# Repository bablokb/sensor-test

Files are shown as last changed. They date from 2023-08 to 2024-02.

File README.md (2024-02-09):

Sensor-Test
===========

This repository contains data and plots of a large scale non-scientifc
comparison test of various temperature/humidity sensors.

Test-Setup
----------

Eight different sensors with a total of 21 units were tested simultaniously
using two Raspberry Pi Picos
(see [Pico-Datalogger](https://github.com/bablokb/pcb-pico-datalogger)).

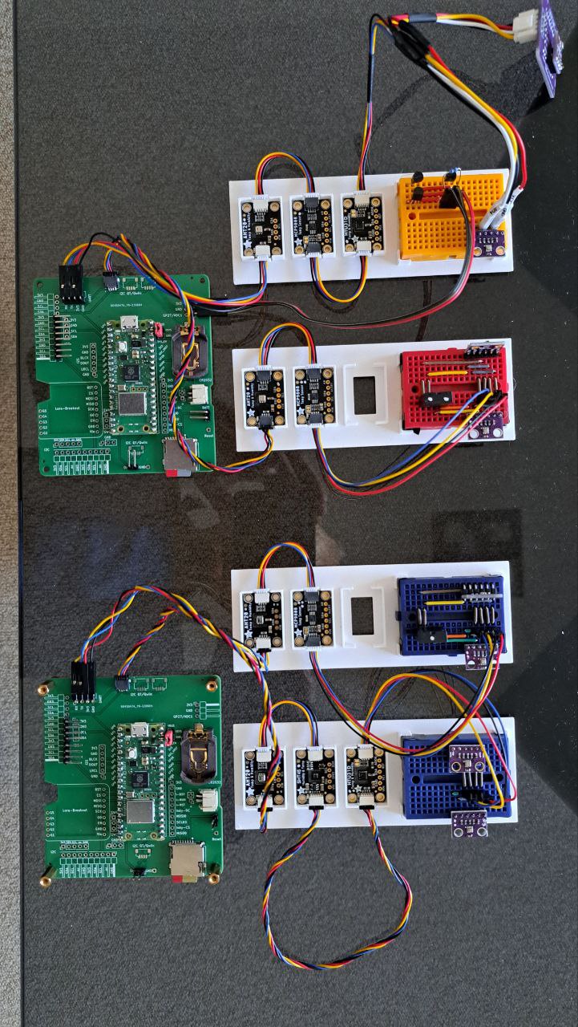
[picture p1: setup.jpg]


Besides normal indoor measurements there were two special phases: one
period within a refrigerator and one within an oven.

Data
----

Raw and processed data is within the [`data`-directory](data/Readme.md).

Besides raw and clean data, there is also a calculated "difference from
mean". Since the setup did not include a high precision reference, this
mean is likely to be the most exact measurement.

Plots
-----

Various plots are within the `plots`-directory. These plots were generated
using <https://github.com/bablokb/py-datamon> which is based on Pandas
and Matplotlib. Configuration-files for the plots are within the
`config`-directory.

Matplotlib allows to zoom into the plots, so for a detailed view of the
data it is recommended to install "py-datamon" and run e.g.

    py-datamon -c configs/bme280-absolute.json data/sensor-test1-combined.csv

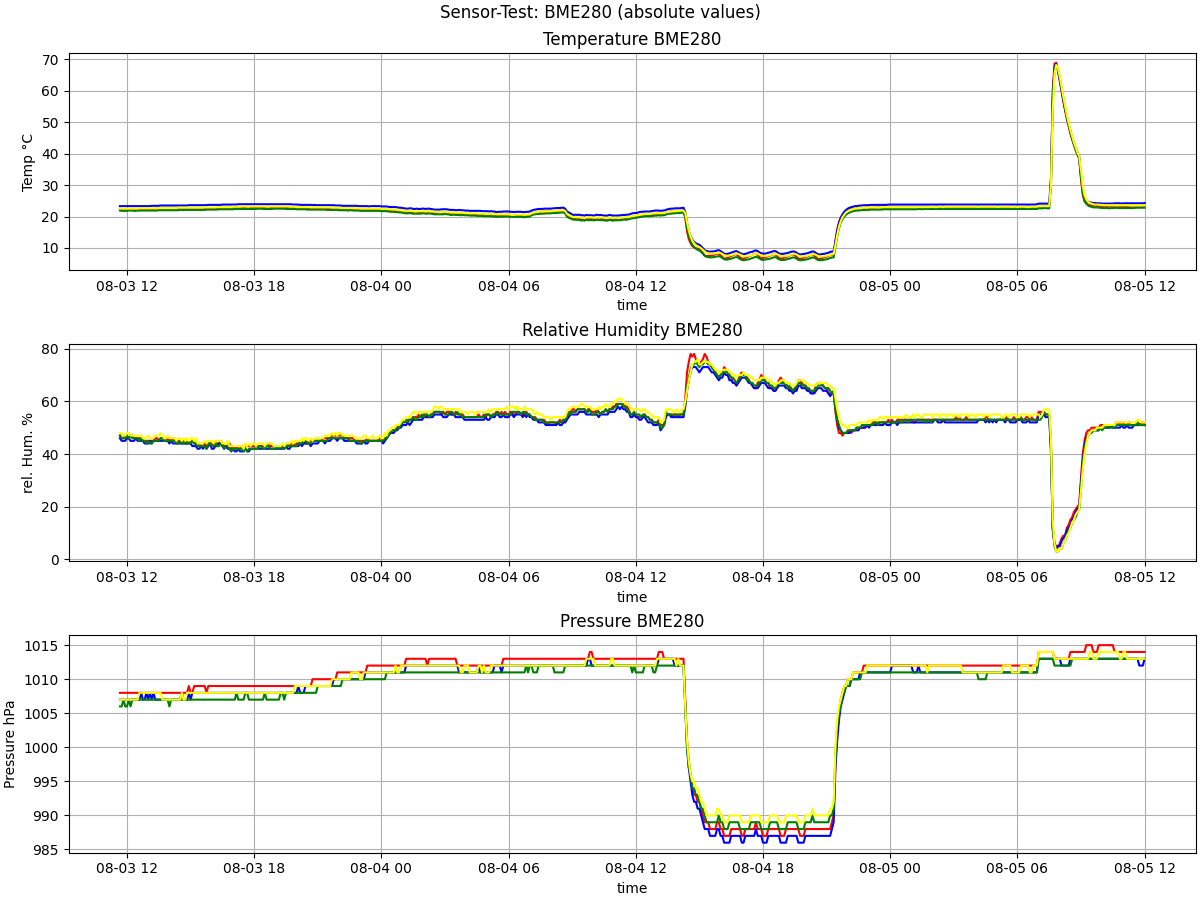
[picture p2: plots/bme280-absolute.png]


Results
-------

The test did not bring up any unexpected results. All sensors are within
the specifications as claimed by their datasheets.

Looking at difference to mean, the cheapest sensor (DS18B20) did the
best job. The main drawback of the DS18B20 is that it only measures
temperature.

Some sensors seem to underestimate (e.g. AHT20, BME280), some seem to
overestimate (e.g. HTU31D). But this is not systematic and not alway true
for all specimen of a sensor, so this should not be seen as a property
of the sensor, but as an artifact of the given measurement series.

All in all, the measurement setup will have a higher influence on the
measured values than the choice of the sensor.

Some Recommendations:

  - Separate sensors from sources that influence the measurements. This
    implies /not/ to use a Pi or even worse a sensor Pi-hat.
  - Shutdown the MCU or at least use deep-sleep modes inbetween
    measurements to minimize heat-creap.
  - Check the sensor-initialization. Some drivers don't use ideal
    setups. The BMx280 is a very good example. The datasheet gives
    advice on how to initialize the sensor but some drivers/docs
    don't make it transparent on what they do. The Arduino-driver
    for the BME280 is perfect in this regard. The driver even provides
    presets to easily switch between settings.

License for the Breakout Holder
-------------------------------

The breakout-holder in the `3D`-directory is licensed under:

[![CC BY-SA 4.0][cc-by-sa-shield]][cc-by-sa]

This work is licensed under a
[Creative Commons Attribution-ShareAlike 4.0 International
License][cc-by-sa].

[][cc-by-sa]

[cc-by-sa]: http://creativecommons.org/licenses/by-sa/4.0/
[cc-by-sa-image]: https://licensebuttons.net/l/by-sa/4.0/88x31.png
[cc-by-sa-shield]:
https://img.shields.io/badge/License-CC%20BY--SA%204.0-lightgrey.svg

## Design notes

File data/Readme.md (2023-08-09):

Data from Measurements
======================

Raw Data
--------

The raw measurement data as recorded by the dataloggers are in
`sensor-test1-ST1-raw.csv` and `sensor-test1-ST2-raw.csv`.

Sensor configuration is in `sensor-test-1.py` and `sensor-test-2.py`.

For a list of columns, see [colums](columns.md).

Clean Data
----------

A few steps were needed to cleanup the data:

  - remove the very first measurement (not within 5 minute grid)
  - adapt time-stamps from xx:xx:06 to xx:xx:00 (just for optics)
  - three observations on ST1 were lost due to a technical issue. Since this
    was in a steady-state situation, these observations were replaced
    with adjacent values (should not change results)

Cleaned data is in `sensor-test1-ST1-clean.csv` and `sensor-test1-ST2-clean.csv`.

Combined Data
-------------

The data was combined with

    grep -v "^#" sensor-test1-ST1-clean.csv >  sensor-test1-ST1-work.csv
    grep -v "^#" sensor-test1-ST2-clean.csv >  sensor-test1-ST2-work.csv
    join -t , -j 1 *work.csv > sensor-test1-combined.csv
    rm *work.csv

Difference to Mean
------------------

The difference to the mean was calculated on the respective columns, i.e.
temperature-mean was calculated for every measurement point across all
temperature measurements and so on for humidity and pressure. This was
done with Pandas using [this script](./calculations.py).

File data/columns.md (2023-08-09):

Columns in the combined data-file
=================================

From first datalogger:

|Column | Value |
|---|---|
| 0| ts |
| 1| battery_1 |
| 2| aht20_1_T |
| 3| aht20_1_H |
|-------|--------------|
| 4| mcp9808_1_T  |
|-------|--------------|
| 5| htu31d_1_T |
| 6| htu31D_1_H |
|-------|--------------|
| 7| bmp280_1_T |
| 8| bmp280_1_P |
|-------|--------------|
| 9| bme280_1_T |
| 10| bme280_1_H |
| 11| bme280_1_P |
|-------|--------------|
| 12| ds18b20_1_T  |
| 13| ds18b20_2_T  |
| 14| ds18b20_3_T  |
|-------|--------------|
| 15| aht20_2_T |
| 16| aht20_2_H |
|-------|--------------|
| 17| mcp9808_2_T  |
|-------|--------------|
| 18| am2320_2_T |
| 19| am2320_2_H |
|-------|--------------|
| 20| bmp280_2_T |
| 21| bmp280_2_P |
|-------|--------------|
| 22| bme280_2_T |
| 23| bme280_2_H |
| 24| bme280_2_P |
|-------|--------------|

From second datalogger:

|Column | Value |
|---|---|
| 25| battery_2 |
|-------|--------------|
| 26| aht20_3_T |
| 27| aht20_3_H |
|-------|--------------|
| 28| mcp9808_3_T  |
|-------|--------------|
| 29| am2320_1_T |
| 30| am2320_1_H |
|-------|--------------|
| 31| bmp280_3_T |
| 32| bmp280_3_P |
|-------|--------------|
| 33| bme280_3_T |
| 34| bme280_3_H |
| 35| bme280_3_P |
|-------|--------------|
| 36| aht20_4_T |
| 37| aht20_4_H |
|-------|--------------|
| 38| sht45_T |
| 39| sht45_H |
|-------|--------------|
| 40| htu31d_2_T |
| 41| htu31D_2_H |
|-------|--------------|
| 42| bmp280_4_T |
| 43| bmp280_4_P |
|-------|--------------
| 44| bme280_4_T |
| 45| bme280_4_H |
| 46| bme280_4_P |
|-------|--------------|

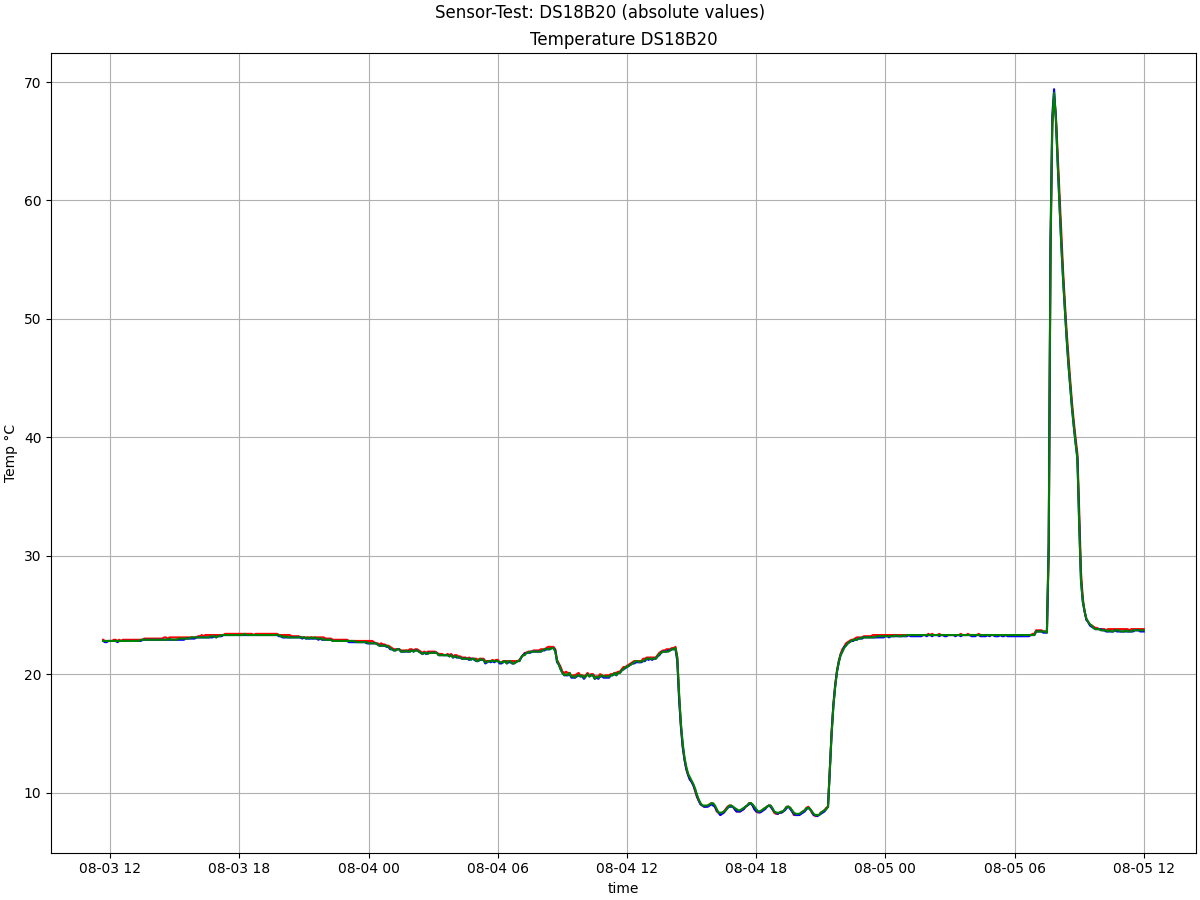
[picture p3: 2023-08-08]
plots/ds18b20-absolute.png

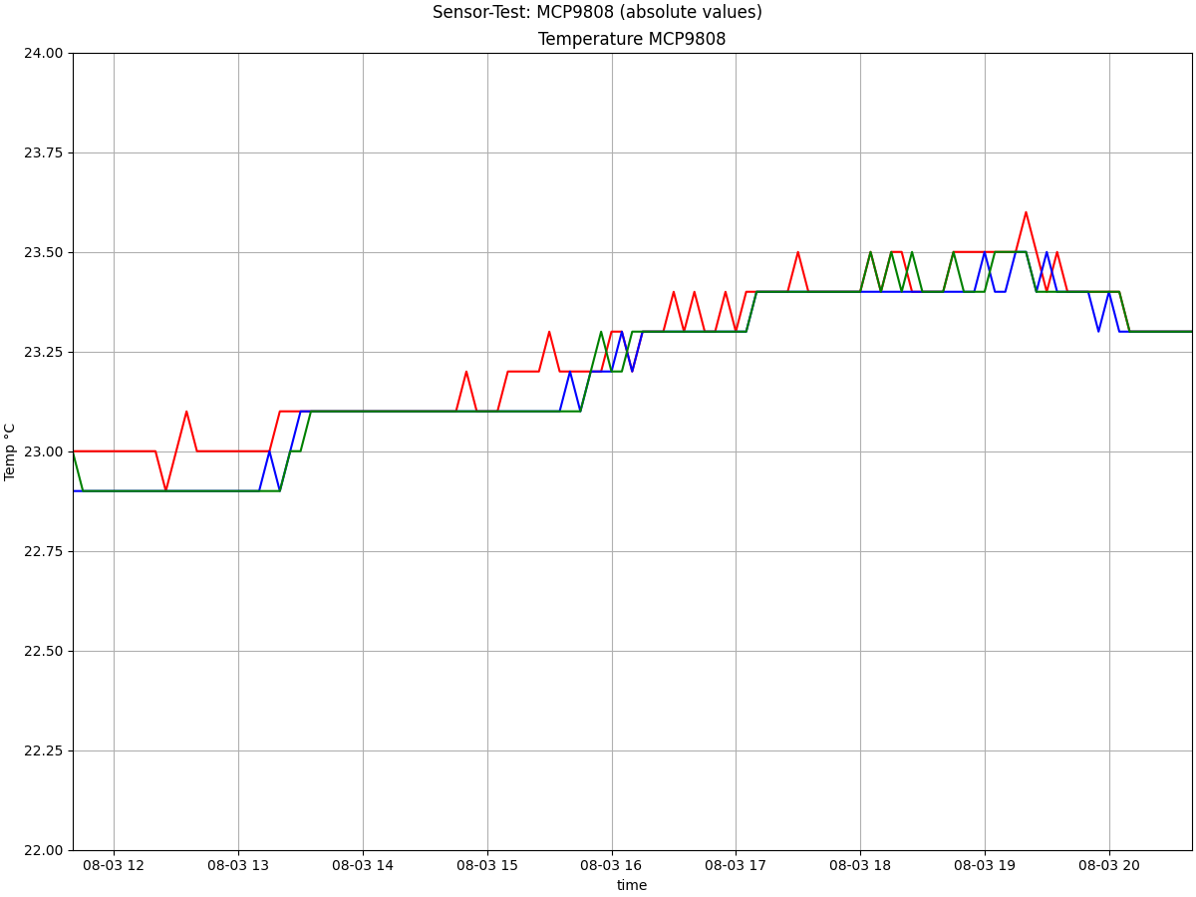
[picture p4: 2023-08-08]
plots/mcp9808-absolute-int1.png

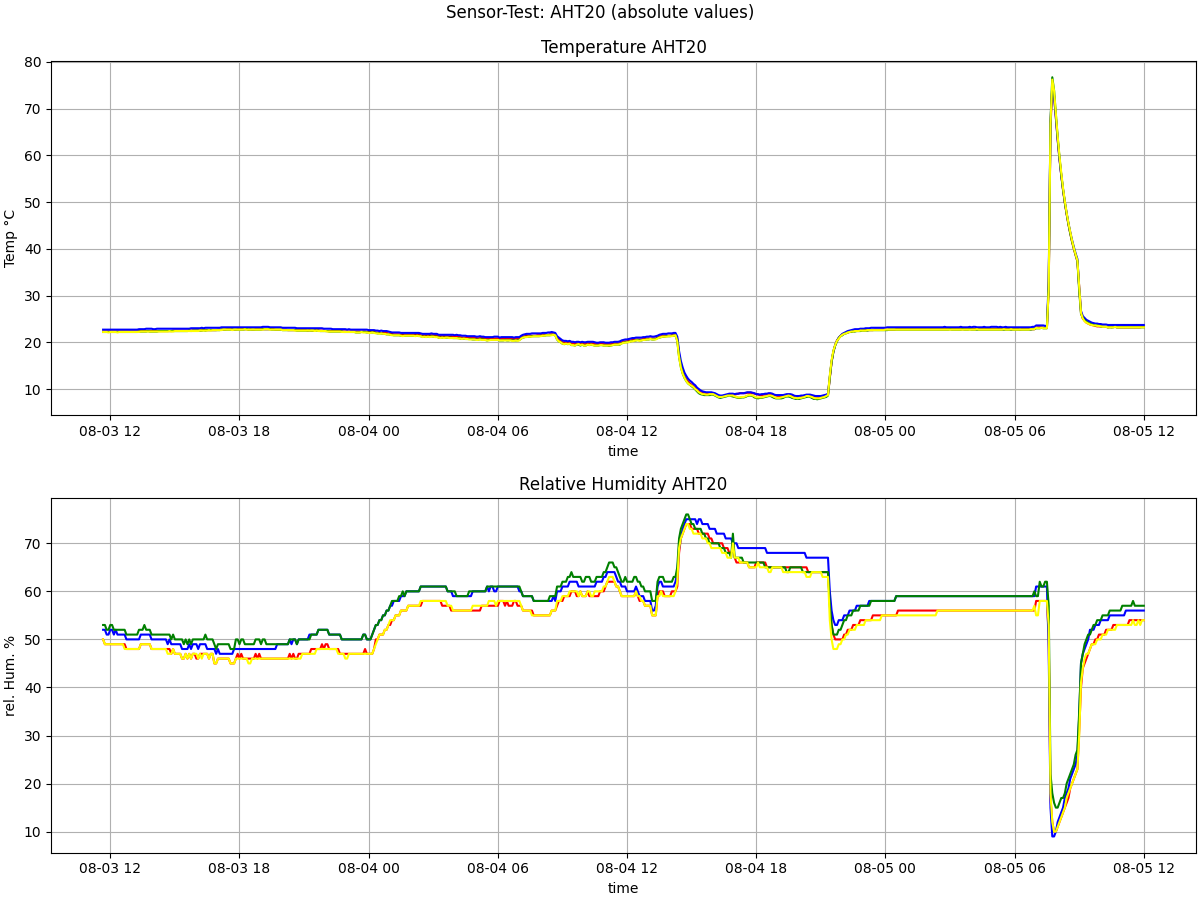
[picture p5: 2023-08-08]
plots/aht20-absolute.png

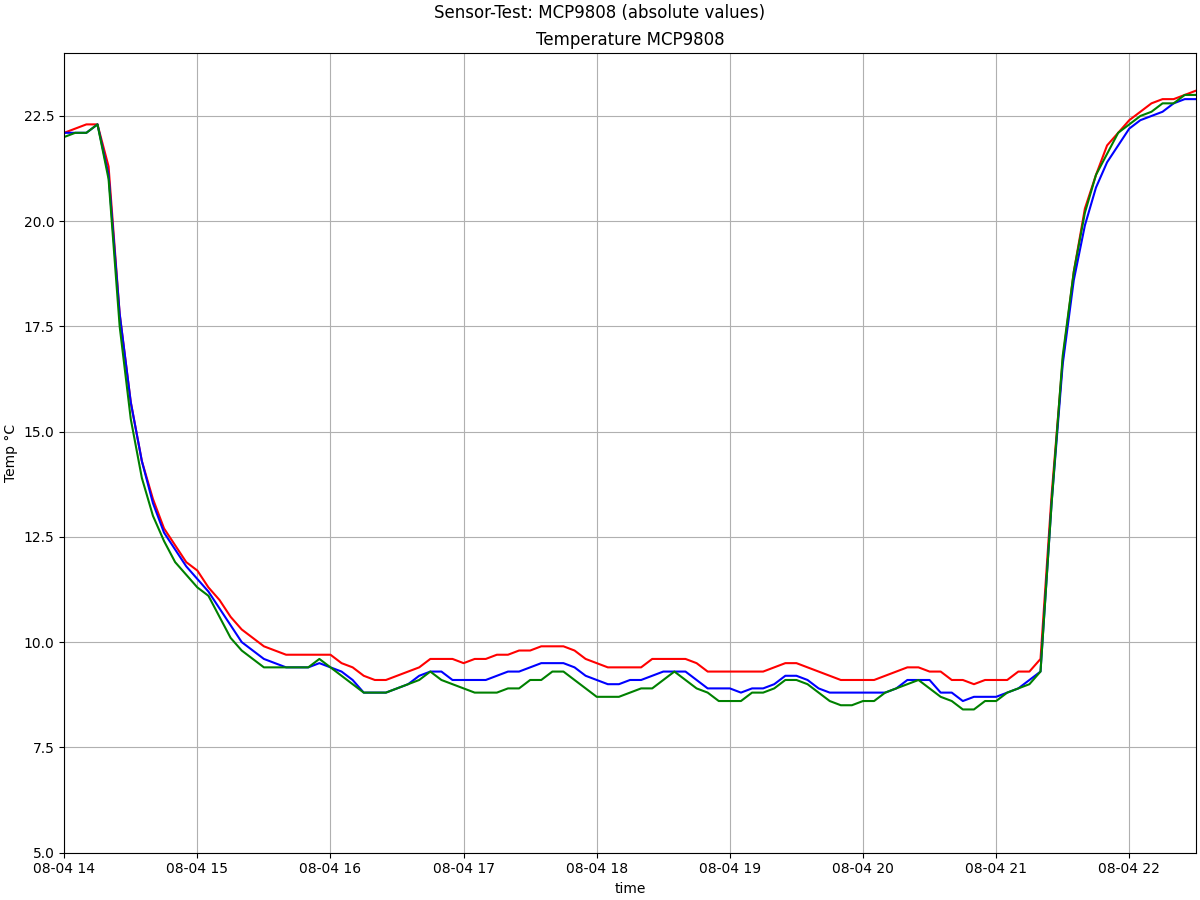
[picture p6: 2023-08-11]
plots/mcp9808-absolute-int2.png

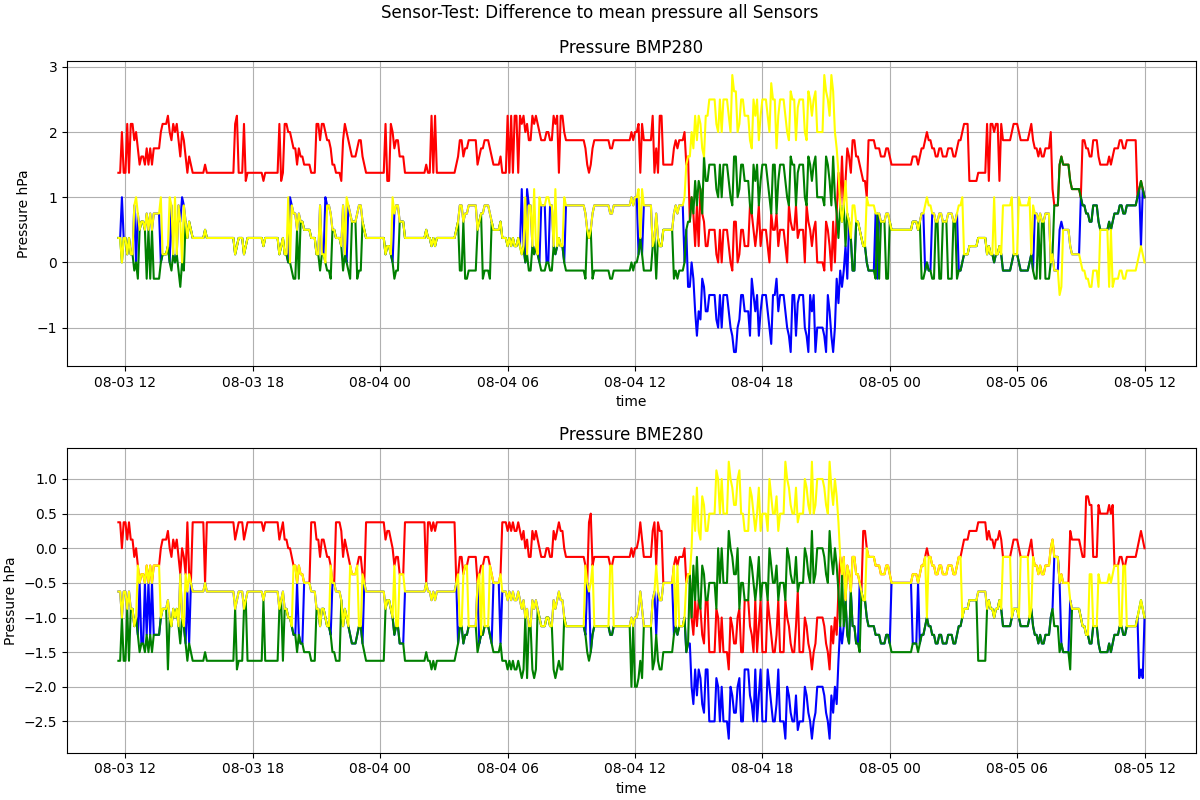
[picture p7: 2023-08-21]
plots/all-press-diff.png

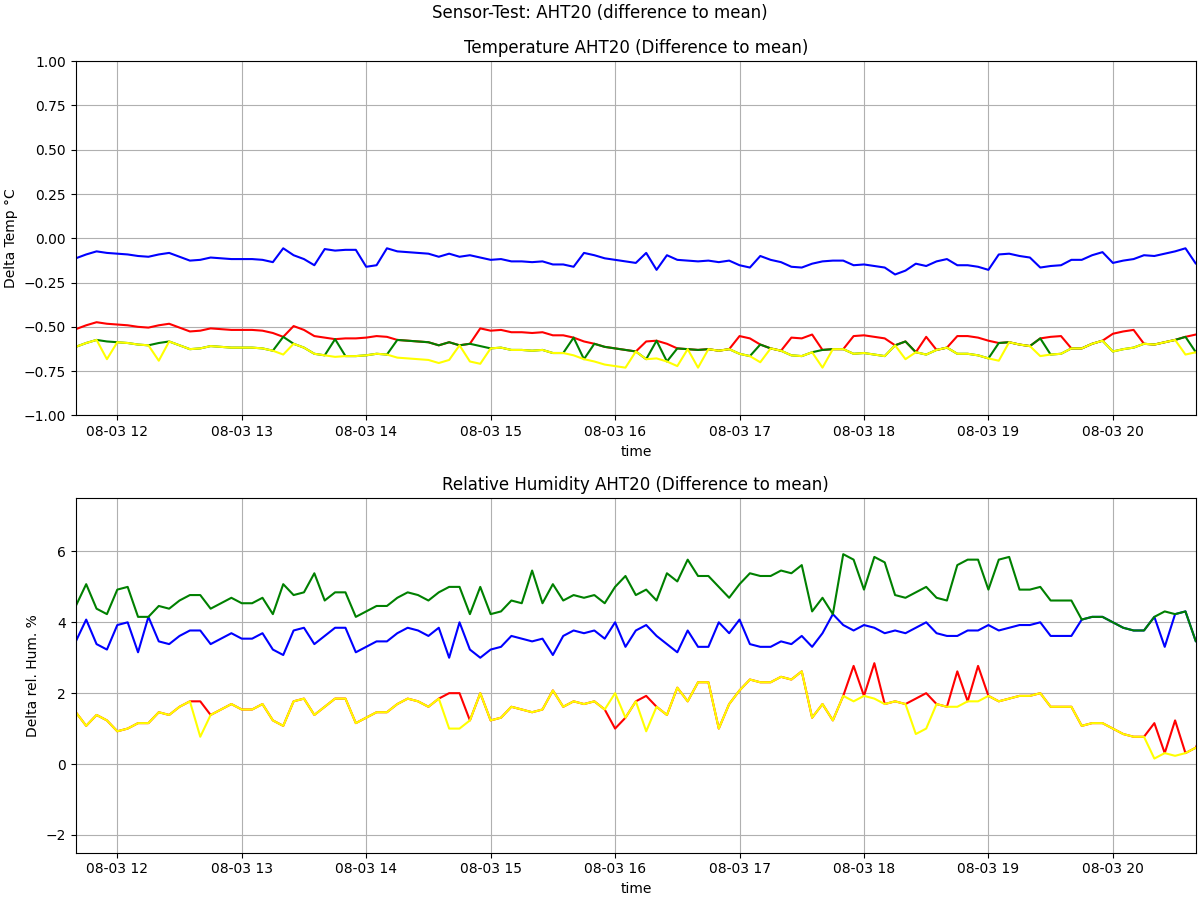
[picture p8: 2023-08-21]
plots/aht20-diff-int1.png

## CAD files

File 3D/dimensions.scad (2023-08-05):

// -----------------------------------------------------------------------------
// 3D-Model (OpenSCAD): basic dimensions for the sensor-holder
//
// Author: Bernhard Bablok
// License: GPL3
//
// https://github.com/bablokb/sensor-test
// -----------------------------------------------------------------------------

$fa = 1;
$fs = 0.4;
$fn = 48;

fuzz = 0.01;
w2 = 0.86;                 // 2 walls Prusa3D
w4 = 1.67;                 // 4 walls Prusa3D
gap = 0.2;                 // gap pcb to case

// dimensions for standard adafruit-breakout   ---------------------------------

x_stemma     = 8;
z_stemma     = 3.2;
z_pcb        = 1.6;

x_breakout      = 17.98 + gap;
y_breakout      = 25.4  + gap;
z_breakout      = z_pcb + z_stemma;

// dimensions for small breadboards   ------------------------------------------

x_bb = 47.3;
y_bb = 35.2;
z_bb = z_breakout;

x_bb_co = x_bb - 10;    // cutout-dimensions
y_bb_co = y_bb - 10;

// dimensions base-plate   -----------------------------------------------------

o_plate = 5;                                             // offset
x_plate = 4*o_plate + 3*(x_breakout+2*w2) + x_bb + 2*w2;
y_plate = 2*o_plate + y_bb + 2*w2;
z_plate = 1.6;
c_plate = 4;                                             // for internal cutouts

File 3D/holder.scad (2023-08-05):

// -----------------------------------------------------------------------------
// 3D-Model (OpenSCAD): A holder for various sensor-breakouts.
//
// Author: Bernhard Bablok
// License: CC-BY-SA
//
// https://github.com/bablokb/sensor-test
// -----------------------------------------------------------------------------

include <dimensions.scad>
include <BOSL2/std.scad>

// --- standard-breakout from Adafruit   ---------------------------------------

module breakout() {
  difference() {
     // wall around breadboard
     rect_tube(size=[x_breakout+2*w2,y_breakout+2*w2],wall=w2,h=z_breakout,
                     anchor=BOTTOM+CENTER);
     // cutouts for Stemma/Qt
     translate([0,-y_breakout/2-w2/2-fuzz,0])
         cuboid([x_stemma,w2+2*fuzz,z_breakout+2*fuzz],anchor=BOTTOM+CENTER);
     translate([0,+y_breakout/2+w2/2+fuzz,0]) 
         cuboid([x_stemma,w2+2*fuzz,z_breakout+2*fuzz],anchor=BOTTOM+CENTER);
   }
   // wall around sensor (not needed for this project)
   // translate([0,y_sensor_off,0])
   //     rect_tube(size=[x_sensor+2*w2,y_sensor+2*w2],wall=w2,h=z_stemma+2*fuzz,
   //               anchor=BOTTOM+CENTER);
}

// --- mini-breadboard   -------------------------------------------------------

module breadboard() {
  difference() {
     // wall around breadboard
     rect_tube(size=[x_bb+2*w2,y_bb+2*w2],wall=w2,h=z_bb,
                     anchor=BOTTOM+CENTER);
     // cutouts to prevent conflicts with extrusions
     translate([-x_bb/2-w2/2-fuzz,0,0])
         cuboid([w2+2*fuzz,y_bb_co,z_bb+2*fuzz],anchor=BOTTOM+CENTER);
     translate([+x_bb/2+w2/2+fuzz,0,0]) 
         cuboid([w2+2*fuzz,y_bb_co,z_bb+2*fuzz],anchor=BOTTOM+CENTER);
     translate([0,-y_bb/2-w2/2-fuzz,0])
         cuboid([x_bb_co,w2+2*fuzz,z_bb+2*fuzz],anchor=BOTTOM+CENTER);
     translate([0,+y_bb/2+w2/2+fuzz,0]) 
         cuboid([x_bb_co,w2+2*fuzz,z_bb+2*fuzz],anchor=BOTTOM+CENTER);
   }
}

// --- cutout below breakout/breadboard   --------------------------------------

module cutout(x,y) {
  cuboid([x-2*c_plate,y-2*c_plate,z_plate+2*fuzz],anchor=BOTTOM+CENTER);
}

// --- base-plate   ------------------------------------------------------------

module base() {
  difference() {
    cuboid([x_plate,y_plate,z_plate],anchor=BOTTOM+CENTER);
    offset1 = -x_plate/2+x_breakout/2+o_plate;
    translate([offset1,0,-fuzz]) cutout(x_breakout,y_breakout);
    offset2 = offset1 + x_breakout+o_plate;
    translate([offset2,0,-fuzz]) cutout(x_breakout,y_breakout);
    offset3 = offset2 + x_breakout+o_plate;
    translate([offset3,0,-fuzz]) cutout(x_breakout,y_breakout);
    offset4 = x_plate/2 - x_bb/2 - o_plate;
    translate([offset4,0,-fuzz]) cutout(x_bb,y_bb);
  }
}

// --- complete holder   -------------------------------------------------------

module holder() {
  base();
  offset1 = -x_plate/2+x_breakout/2+o_plate;
  translate([offset1,0,z_plate-fuzz]) breakout();
  offset2 = offset1 + x_breakout+o_plate;
  translate([offset2,0,z_plate-fuzz]) breakout();
  offset3 = offset2 + x_breakout+o_plate;
  translate([offset3,0,z_plate-fuzz]) breakout();
  offset4 = x_plate/2 - x_bb/2 - o_plate;
  translate([offset4,0,z_plate-fuzz]) breadboard();
}

// --- final model   -----------------------------------------------------------

holder();

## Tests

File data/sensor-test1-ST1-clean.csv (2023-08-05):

#ID: ST1
#Location: 56JR+G5 FFB
#ts | Bat V | T/AHT °C | H/AHT %rH | T/MCP °C | T/HTU °C | H/HTU %rH | T/BMP °C | P/BMP | T/BME °C | H/BME %rH | P/BME | T/18B °C | T/18B °C | T/18B °C | T/AHT °C | H/AHT %rH | T/MCP °C | T/AM °C | H/AM %rH | T/BMP °C | P/BMP | T/BME °C | H/BME %rH | P/BME
2023-08-03T11:40:00 | 2.77 | 22.3 | 50 | 23.0 | 23.2 | 50 | 23.0 | 1009 | 22.4 | 47 | 1008 | 22.9 | 22.8 | 22.8 | 22.7 | 52 | 22.9 | 22.6 | 44 | 23.3 | 1008 | 23.3 | 46 | 1007
2023-08-03T11:45:00 | 2.91 | 22.3 | 49 | 23.0 | 23.2 | 49 | 22.9 | 1009 | 22.4 | 46 | 1008 | 22.8 | 22.7 | 22.8 | 22.7 | 52 | 22.9 | 22.5 | 43 | 23.3 | 1008 | 23.3 | 45 | 1007
2023-08-03T11:50:00 | 2.78 | 22.3 | 49 | 23.0 | 23.1 | 49 | 22.9 | 1010 | 22.3 | 46 | 1008 | 22.8 | 22.7 | 22.8 | 22.7 | 51 | 22.9 | 22.5 | 43 | 23.2 | 1009 | 23.3 | 45 | 1007
2023-08-03T11:55:00 | 2.90 | 22.3 | 49 | 23.0 | 23.2 | 49 | 22.9 | 1009 | 22.3 | 47 | 1008 | 22.8 | 22.8 | 22.8 | 22.7 | 51 | 22.9 | 22.5 | 43 | 23.2 | 1008 | 23.3 | 45 | 1007
2023-08-03T12:00:00 | 2.91 | 22.3 | 49 | 23.0 | 23.1 | 49 | 22.9 | 1009 | 22.3 | 46 | 1008 | 22.8 | 22.8 | 22.8 | 22.7 | 52 | 22.9 | 22.6 | 43 | 23.3 | 1008 | 23.3 | 46 | 1007
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

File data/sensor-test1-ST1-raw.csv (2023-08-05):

#ID: ST1
#Location: 56JR+G5 FFB
#ts | Bat V | T/AHT °C | H/AHT %rH | T/MCP °C | T/HTU °C | H/HTU %rH | T/BMP °C | P/BMP | T/BME °C | H/BME %rH | P/BME | T/18B °C | T/18B °C | T/18B °C | T/AHT °C | H/AHT %rH | T/MCP °C | T/AM °C | H/AM %rH | T/BMP °C | P/BMP | T/BME °C | H/BME %rH | P/BME
2023-08-03T11:38:45 | 2.79 | 22.3 | 50 | 22.9 | 23.1 | 50 | 22.9 | 1009 | 22.3 | 47 | 1008 | 22.8 | 22.7 | 22.8 | 22.7 | 52 | 22.9 | 22.5 | 44 | 23.3 | 1008 | 23.3 | 46 | 1007
2023-08-03T11:40:06 | 2.77 | 22.3 | 50 | 23.0 | 23.2 | 50 | 23.0 | 1009 | 22.4 | 47 | 1008 | 22.9 | 22.8 | 22.8 | 22.7 | 52 | 22.9 | 22.6 | 44 | 23.3 | 1008 | 23.3 | 46 | 1007
2023-08-03T11:45:06 | 2.91 | 22.3 | 49 | 23.0 | 23.2 | 49 | 22.9 | 1009 | 22.4 | 46 | 1008 | 22.8 | 22.7 | 22.8 | 22.7 | 52 | 22.9 | 22.5 | 43 | 23.3 | 1008 | 23.3 | 45 | 1007
2023-08-03T11:50:06 | 2.78 | 22.3 | 49 | 23.0 | 23.1 | 49 | 22.9 | 1010 | 22.3 | 46 | 1008 | 22.8 | 22.7 | 22.8 | 22.7 | 51 | 22.9 | 22.5 | 43 | 23.2 | 1009 | 23.3 | 45 | 1007
2023-08-03T11:55:06 | 2.90 | 22.3 | 49 | 23.0 | 23.2 | 49 | 22.9 | 1009 | 22.3 | 47 | 1008 | 22.8 | 22.8 | 22.8 | 22.7 | 51 | 22.9 | 22.5 | 43 | 23.2 | 1008 | 23.3 | 45 | 1007
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

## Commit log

2023-08-05 added test1 raw-data
    [sensor-test1-ST1-raw.csv, sensor-test1-ST2-raw.csv]
2023-08-05 added cleaned and combined data
    [sensor-test1-ST1-clean.csv, sensor-test1-ST2-clean.csv, sensor-test1-combined.csv]
2023-08-08 add temperature-diff from mean
    [sensor-test1-diff.csv]
2023-08-09 add pressure-diff from mean
2023-08-09 added converted data: difference to mean
    [sensor-test1-diff.csv]
